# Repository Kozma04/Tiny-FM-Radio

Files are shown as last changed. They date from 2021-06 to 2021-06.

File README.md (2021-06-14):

# Tiny FM Radio v1 [Work in progress]
A small battery-powered FM Radio powered by the ATtiny3216 microcontroller.
Project sponsored by JLCPCB (https://jlcpcb.com/RAT)

It was originally intented to use the SI4703 FM tuner and some other ICs, but due to some PCB design mistakes and since this was originally a birthday project for my mother and I had to finish it ASAP, I was forced to drop some features for now and integrate in the project an FM tuner kit based on the HEX3653 IC I found at a local electronic components store.

This project's code is using SpenceKonde's megaTinyCore: https://github.com/SpenceKonde/megaTinyCore

# Present features
  * SH1106 monochrome OLED display (128x64 px, I2C interface)
  * TPA2005D1 1.4W audio amplifier fed by a PAM2401 5V/1A boost converter
  * 2W / 8Ohm speaker
  * 6 tactile buttons (up, down, left, right, ok and power)
  * 1200mAh LiPo battery
  * MCP73831 500mA LiPo / Li-Ion battery charger IC
  * Micro USB port for battery charging
  * AP2127K-3.3TRG1 3.3V / 400mA voltage regulator to supply the ICs. Uses the PAM2401 5V supply as input
  * ATtiny3216 microcontroller. Features:
    * Controls the HEX3653 FM tuner and the shutdown pins of the TPA2005D1 and PAM2401 ICs via a menu displayed on the OLED
    * Monitors the battery voltage
    * Shuts down the 5V supply when the battery voltage reaches a critical voltage

# Planned features (possible after fixing the PCB model)
  * SI4703-C19 FM tuner IC featuring volume control, RDS and more (needs external 32.768Khz oscillator)
  * Timekeeping using the MCP79402 real-time clock

Here is how the project looks like. __[Watch video!](https://youtu.be/wYINLay8BuY)__

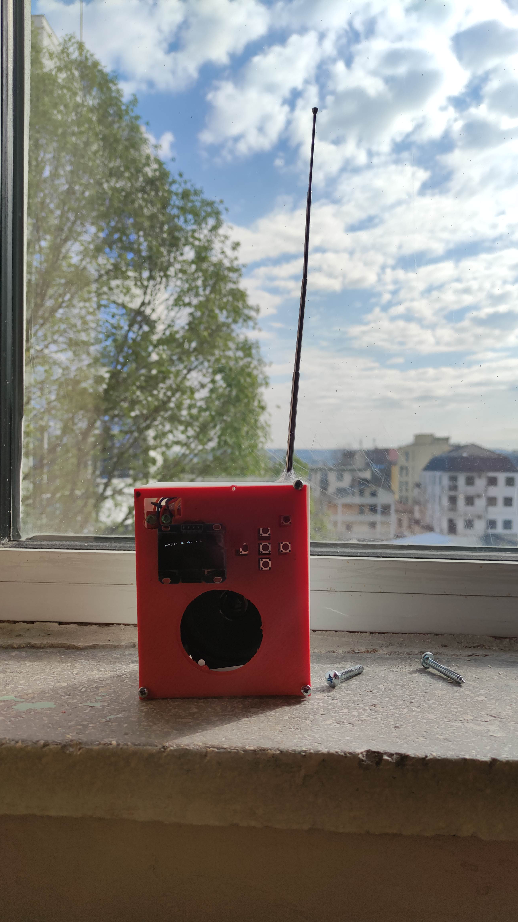
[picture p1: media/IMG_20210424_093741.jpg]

This was my first 3D Printed case :)

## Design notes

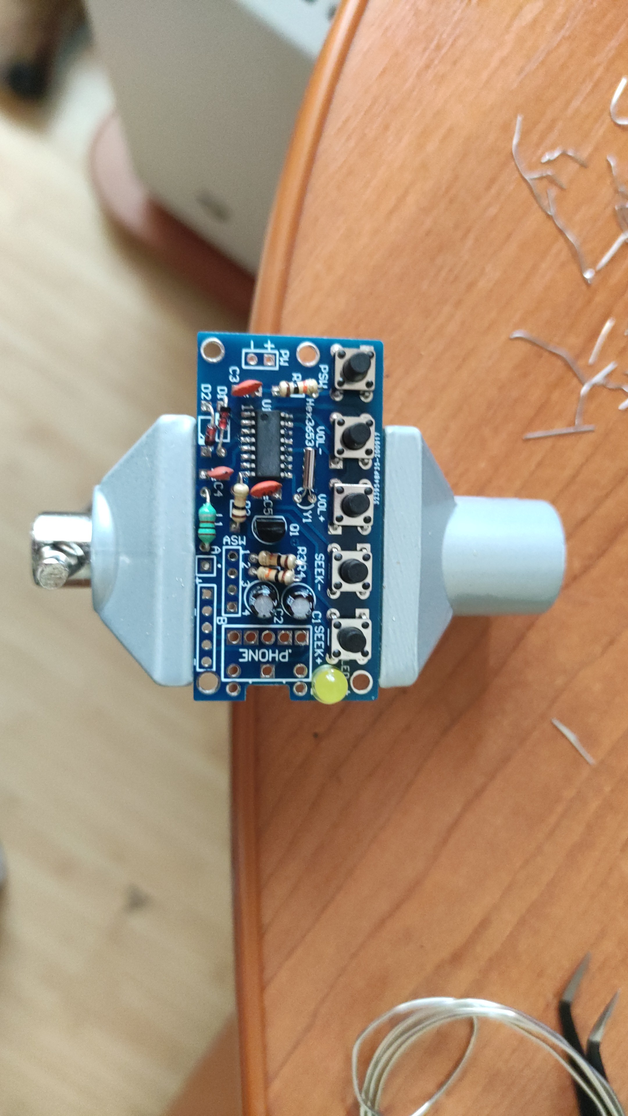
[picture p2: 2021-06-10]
media/IMG-20210422-WA0003.jpeg

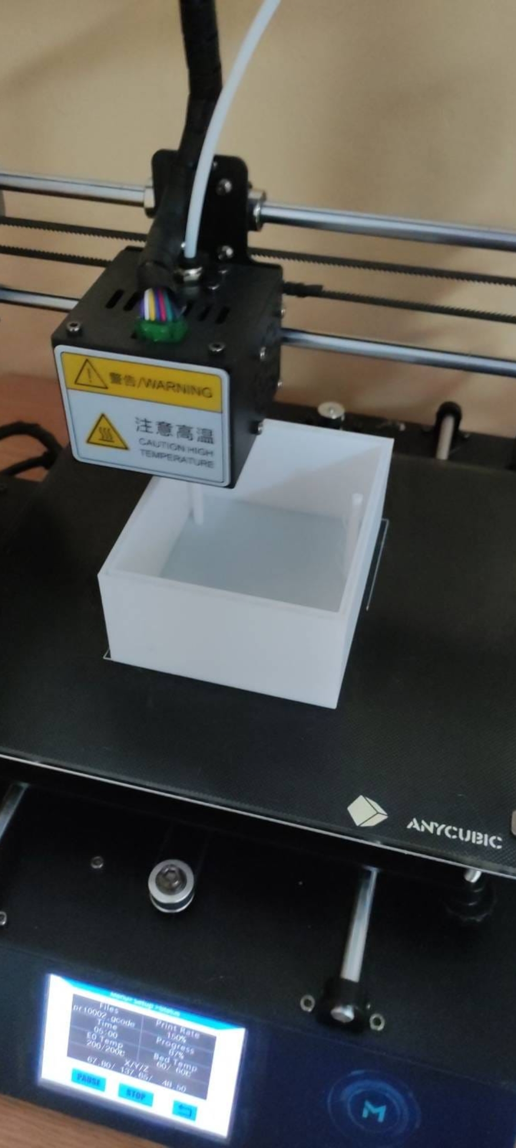
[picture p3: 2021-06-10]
media/wip.jpg

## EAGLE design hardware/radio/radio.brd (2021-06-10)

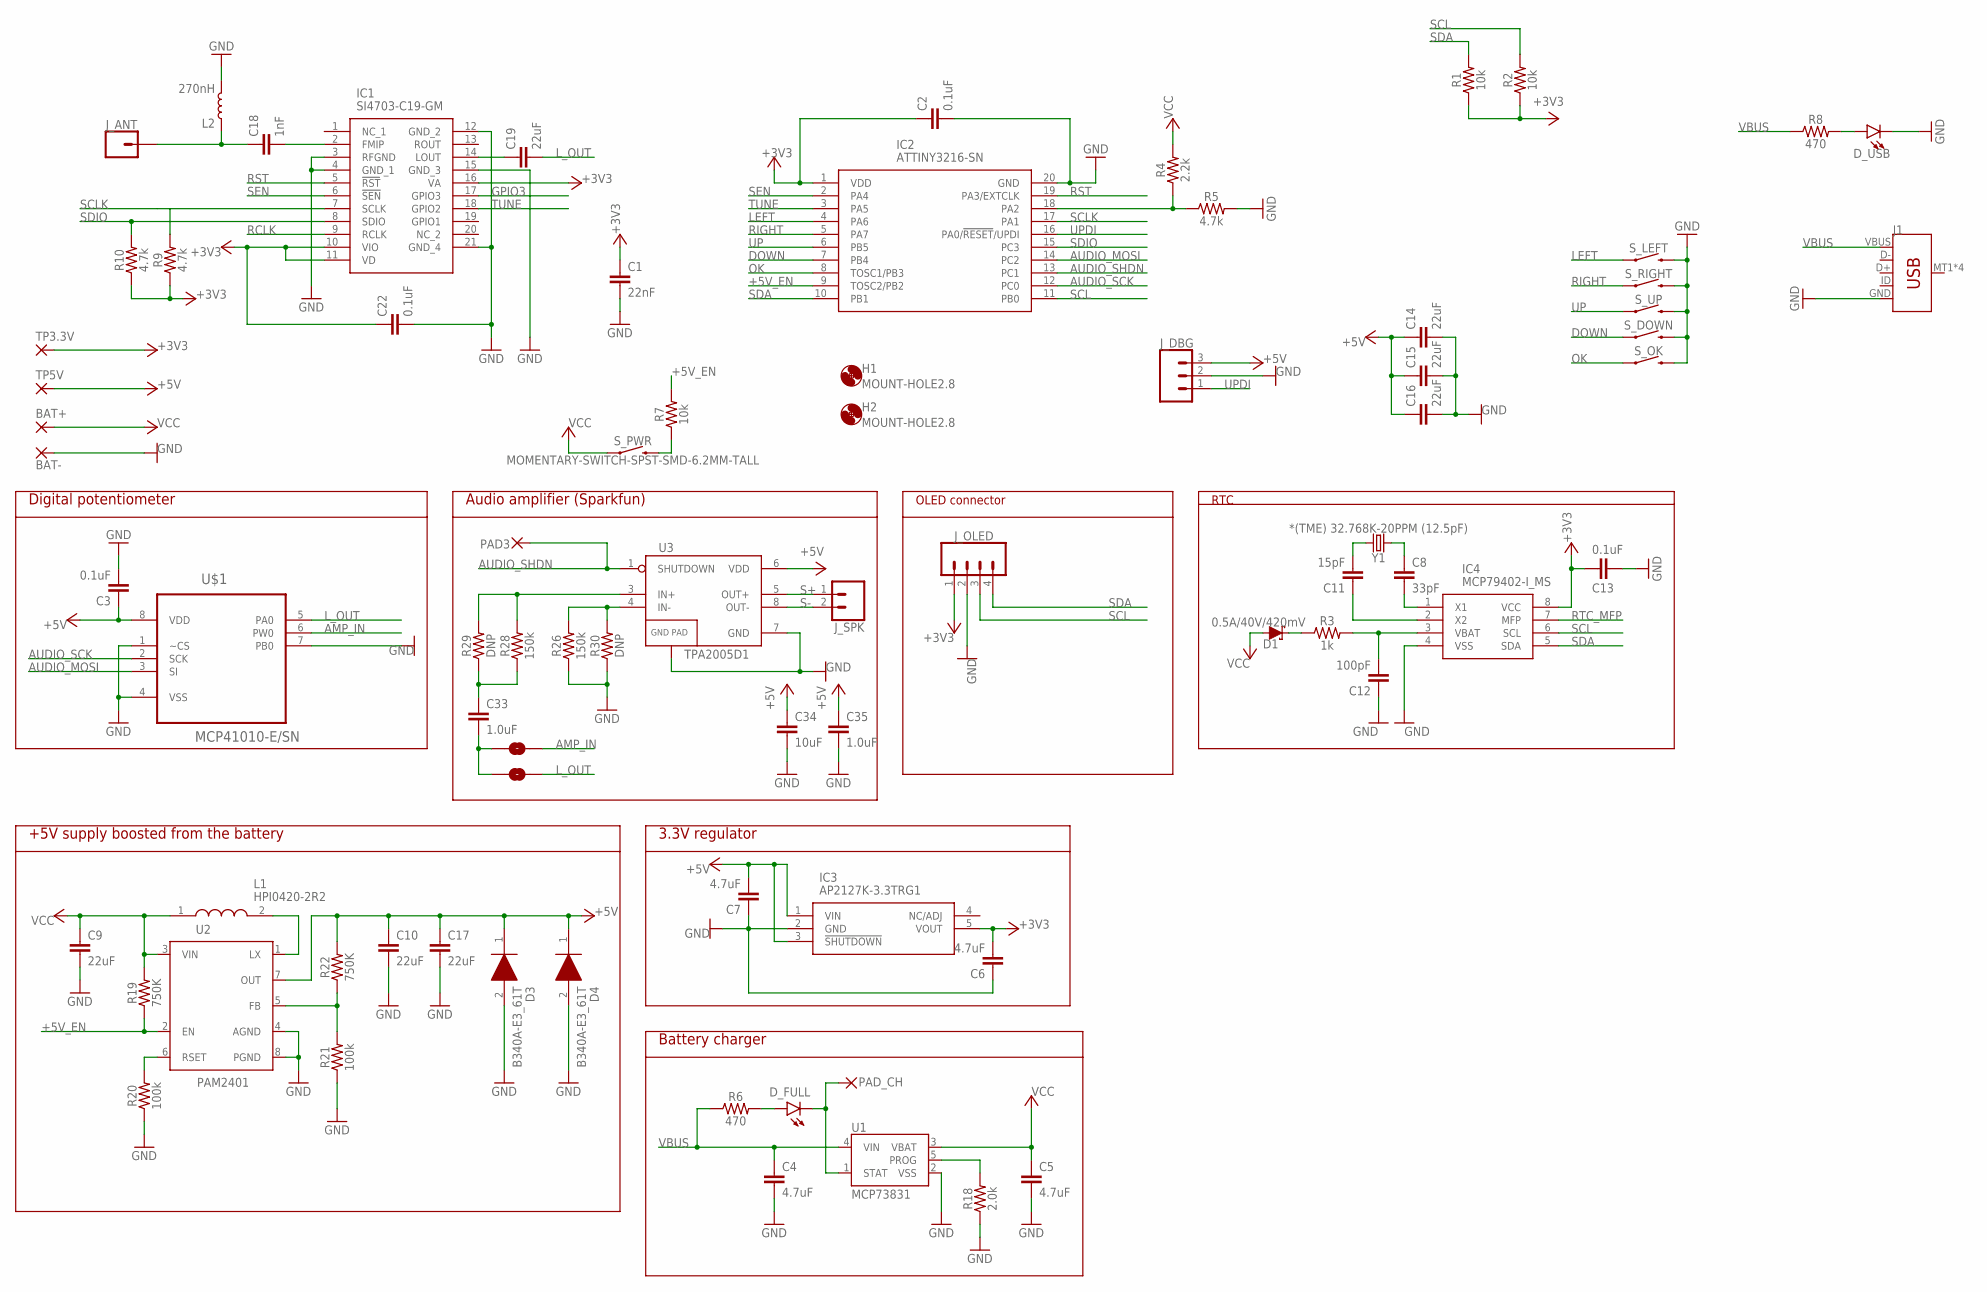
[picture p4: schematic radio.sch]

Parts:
BAT+: SMD2; SMD1,27-2,54
BAT-: SMD2; SMD1,27-2,54
C1: 22nF; 0603
C2, C3, C13, C22: 0.1uF; 0603
C4, C5, C6, C7: 4.7uF; 0603
C8: 33pF; 0603
C9, C10, C14, C15, C16, C17, C19: 22uF; 0805
C11: 15pF; 0603
C12: 100pF; 0603
C18: 1nF; 0603
C33, C35: 1.0uF; 0603
C34: 10uF; 0805
D1: 0.5A/40V/420mV; SOD-323
D3, D4: B340A-E3_61T; DIOM5127X229N
D_FULL: RED; LED_5MM
D_USB: LED5MM; LED_5MM
H1, H2: MOUNT-HOLE2.8; 2,8
IC1: SI4703-C19-GM; SI4703C19GM
IC2: ATTINY3216-SN; SOIC127P1030X265-20N
IC3: AP2127K-3.3TRG1; SOT95P282X145-5N
IC4: MCP79402-I_MS; SOP65P490X110-8N
J1: USB_MICRO-B_SMT; USB-MICROB
JP1, JP2: JUMPER-SMT_2_NO_NO-SILK; SMT-JUMPER_2_NO_NO-SILK
J_ANT: CONN_01; 1X01
J_DBG: CONN_03LOCK; 1X03_LOCK
J_OLED: CONN_04LOCK; 1X04_LOCK
J_SPK: CONN_02; 1X02
L1: HPI0420-2R2; HPI04202R2
L2: 270nH; 0805
PAD3: SMD2; SMD1,27-2,54
PAD_CH: SMD2; SMD1,27-2,54
R1, R2, R7: 10k; 0603
R3: 1k; 0603
R4: 2.2k; 0603
R5, R9, R10: 4.7k; 0603
R6, R8: 470; 0603
R18: 2.0k; 0603
R19, R22: 750K; 0603
R20, R21: 100k; 0603
R26, R28: 150k; 0603
R29, R30: DNP; 0603
S_DOWN: MOMENTARY-SWITCH-SPST-SMD-6.2MM-TALL; TACTILE_SWITCH_SMD_6.2MM_TALL
S_LEFT: MOMENTARY-SWITCH-SPST-SMD-6.2MM-TALL; TACTILE_SWITCH_SMD_6.2MM_TALL
S_OK: MOMENTARY-SWITCH-SPST-SMD-6.2MM-TALL; TACTILE_SWITCH_SMD_6.2MM_TALL
S_PWR: MOMENTARY-SWITCH-SPST-SMD-6.2MM-TALL; TACTILE_SWITCH_SMD_6.2MM_TALL
S_RIGHT: MOMENTARY-SWITCH-SPST-SMD-6.2MM-TALL; TACTILE_SWITCH_SMD_6.2MM_TALL
S_UP: MOMENTARY-SWITCH-SPST-SMD-6.2MM-TALL; TACTILE_SWITCH_SMD_6.2MM_TALL
TP3.3V, TP5V: SMD2; SMD1,27-2,54
U1: MCP73831; SOT23-5
U2: PAM2401; MSOP8
U3: TPA2005D1; POWER-SOP8
U$1: MCP41010-E/SN; SOIC127P600X175-8N
Y1: *(TME) 32.768K-20PPM (12.5pF); CRYSTAL-PTH-2X6-CYL

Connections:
+3V3: C1.1, C2.1, C3.1, C6.2, C13.2, C22.1, IC1.10 (VIO), IC1.11 (VD), IC1.16 (VA), IC2.1 (VDD), IC3.5 (VOUT), IC4.8 (VCC), J_OLED.1, R1.1, R2.1, R9.1, R10.1, TP3.3V.1, U$1.8 (VDD)
+5V: C7.2, C10.1, C14.1, C15.1, C16.1, C17.1, C34.1, C35.1, D3.1 (K), D4.1 (K), IC3.1 (VIN), IC3.3 (!SHUTDOWN), J_DBG.3, R22.2, TP5V.1, U2.7 (OUT), U3.6 (VDD)
+5V_EN: IC2.9 (TOSC2/PB2), R7.2, R19.1, U2.2 (EN)
AMP_IN: JP1.2, U$1.6 (PW0)
AUDIO_MOSI: IC2.14 (PC2), U$1.3 (SI)
AUDIO_SCK: IC2.12 (PC0), U$1.2 (SCK)
AUDIO_SHDN: IC2.13 (PC1), PAD3.1, U3.1 (SHUTDOWN)
DOWN: IC2.7 (PB4), S_DOWN.A2 (1)
GND: BAT-.1, C1.2, C2.2, C3.2, C4.2, C5.2, C6.1, C7.1, C9.2, C10.2, C12.1, C13.1, C14.2, C15.2, C16.2, C17.2, C22.2, C34.2, C35.2, D3.2 (A), D4.2 (A), D_USB.K (C), IC1.3 (RFGND), IC1.4 (GND_1), IC1.12 (GND_2), IC1.15 (GND_3), IC1.21 (GND_4), IC2.20 (GND), IC3.2 (GND), IC4.4 (VSS), J1.GND, J_DBG.2, J_OLED.2, L2.2, R5.2, R18.1, R20.1, R21.1, R26.1, R30.1, S_DOWN.B2 (2), S_LEFT.B2 (2), S_OK.B2 (2), S_RIGHT.B2 (2), S_UP.B2 (2), U1.2 (VSS), U2.4 (AGND), U2.8 (PGND), U3.7 (GND), U3.9 (GND), U$1.1 (~CS), U$1.4 (VSS), U$1.7 (PB0)
GPIO3: IC1.17 (GPIO3)
LEFT: IC2.4 (PA6), S_LEFT.A2 (1)
L_OUT: C19.2, JP2.2, U$1.5 (PA0)
unnamed: C18.2, IC1.2 (FMIP)
unnamed: C8.1, Y1.1
unnamed: C8.2, IC4.1 (X1)
unnamed: D_FULL.K (C), PAD_CH.1, U1.1 (STAT)
unnamed: D_FULL.A, R6.2
unnamed: C11.2, Y1.2
unnamed: C11.1, IC4.2 (X2)
unnamed: C12.2, IC4.3 (VBAT), R3.2
unnamed: D1.C, R3.1
unnamed: R18.2, U1.5 (PROG)
unnamed: R20.2, U2.6 (RSET)
unnamed: IC2.18 (PA2), R4.1, R5.1
unnamed: R7.1, S_PWR.B2 (2)
unnamed: D_USB.A, R8.2
unnamed: C18.1, J_ANT.1, L2.1
unnamed: C19.1, IC1.14 (LOUT)
unnamed: L1.2, U2.1 (LX)
unnamed: R21.2, R22.1, U2.5 (FB)
unnamed: R28.2, R29.2, U3.3 (IN+)
unnamed: R26.2, R30.2, U3.4 (IN-)
unnamed: C33.1, R28.1, R29.1
unnamed: C33.2, JP1.1, JP2.1
OK: IC2.8 (TOSC1/PB3), S_OK.A2 (1)
RCLK: IC1.9 (RCLK)
RIGHT: IC2.5 (PA7), S_RIGHT.A2 (1)
RST: IC1.5 (!RST), IC2.19 (PA3/EXTCLK)
RTC_MFP: IC4.7 (MFP)
S+: J_SPK.1, U3.5 (OUT+)
S-: J_SPK.2, U3.8 (OUT-)
SCL: IC2.11 (PB0), IC4.6 (SCL), J_OLED.3, R2.2
SCLK: IC1.7 (SCLK), IC2.17 (PA1), R9.2
SDA: IC2.10 (PB1), IC4.5 (SDA), J_OLED.4, R1.2
SDIO: IC1.8 (SDIO), IC2.15 (PC3), R10.2
SEN: IC1.6 (!SEN), IC2.2 (PA4)
TUNE: IC1.18 (GPIO2), IC2.3 (PA5)
UP: IC2.6 (PB5), S_UP.A2 (1)
UPDI: IC2.16 (PA0/!RESET!/UPDI), J_DBG.1
VBUS: C4.1, J1.VBUS, R6.1, R8.1, U1.4 (VIN)
VCC: BAT+.1, C5.1, C9.1, D1.A, L1.1, R4.2, R19.2, S_PWR.A2 (1), U1.3 (VBAT), U2.3 (VIN)

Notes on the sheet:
Digital potentiometer
Audio amplifier (Sparkfun)
+5V supply boosted from the battery
3.3V regulator
Battery charger
OLED connector
RTC

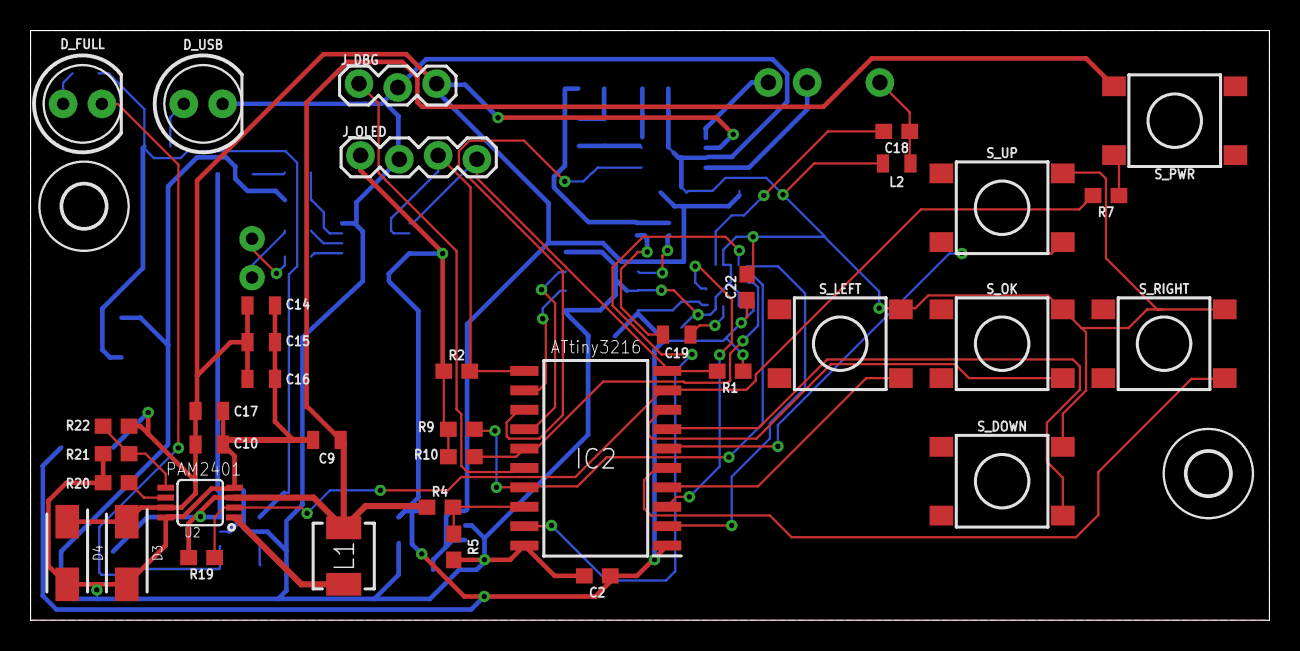
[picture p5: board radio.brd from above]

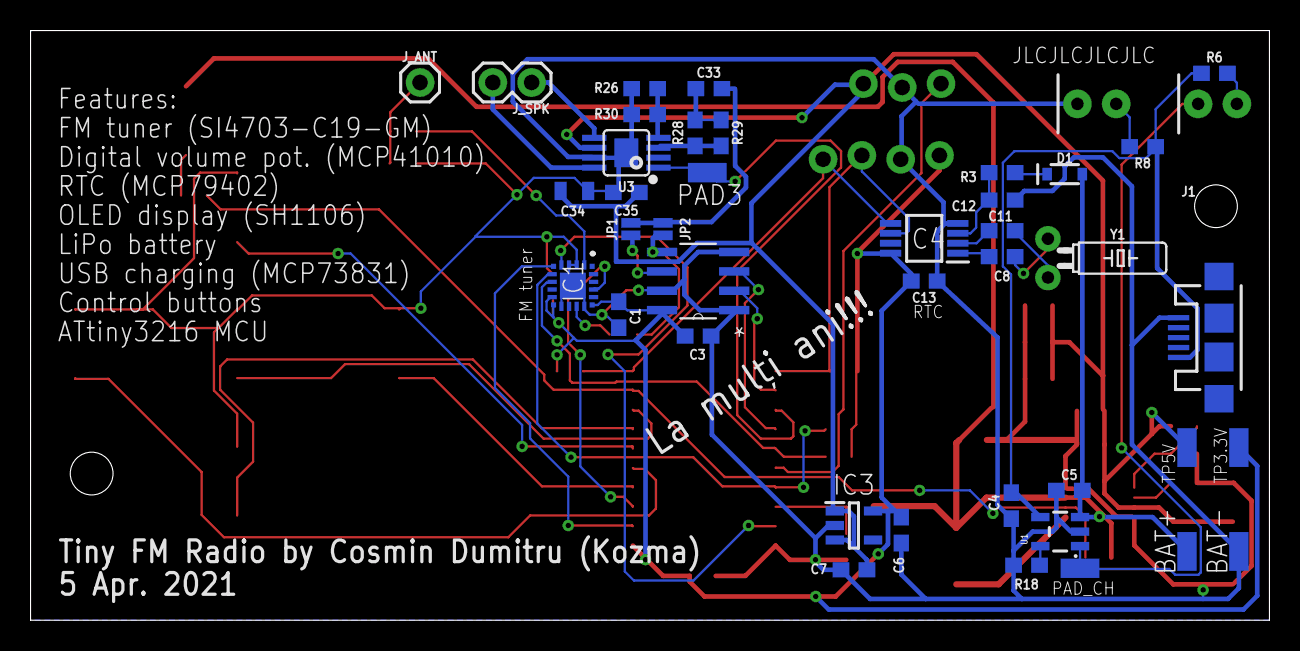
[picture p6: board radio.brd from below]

Board: 2 copper layers, 81.1 x 38.6 mm, 79 parts (40 on the bottom side), 48 nets.

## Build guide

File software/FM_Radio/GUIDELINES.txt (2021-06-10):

81.1mm x 38.6mm PCB
PCB drill 1: 3.5mm x 27.1mm
PCB drill 2: 77.1mm x 9.6mm
PCB drill diameter: 2.8mm
Holder PCB drill diameter: 4.2mm

Button dimensions: 6.2mm x 6.2mm
Power button: 74.9 x 32.7
Up: 63.6 x 27
Down: 63.6 x 9.1
Left: 53 x 18.1
Right: 74.2 x 18.1
Ok: 63.6 x 18.1

OLED header: 21.6 x 30.3

OFFSET LEFT AND RIGHT SIDES BY 1.2MM!

0.5mm tolerance
2.5mm thickness

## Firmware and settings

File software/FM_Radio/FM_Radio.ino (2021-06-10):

#include <Wire.h>
#include "font5x7.h"
#include "tinytwi.h"
#include "SH1106.h"

#define PIN_PWR   PIN_PB2
#define PIN_BAT   PIN_PA2
#define PIN_OK    PIN_PB3
#define PIN_UP    PIN_PB5
#define PIN_DOWN  PIN_PB4
#define PIN_LEFT  PIN_PA6
#define PIN_RIGHT PIN_PA7
#define PIN_ASHDN PIN_PC1

#define PIN_PSW   PIN_PA4
#define PIN_VOLM  PIN_PC3
#define PIN_VOLP  PIN_PC0
#define PIN_SEEKM PIN_PA1
#define PIN_SEEKP PIN_PA3

enum Action {
    LEFT, RIGHT, OK
};

struct Entry {
    char name[24] = {0};
    void (*callback)(Entry*, Action) = 0;
};

struct Menu {
    char name[16] = {0};
    Entry *entries[7];
    uint8_t nEntries;
};

Menu *menu;

uint8_t hovered;
bool mute = false;
int volume;

void renderMenu() {
    oled.clear();
    oled.setCursor(0, 0);
    oled.fontColor = INVERSE;
    oled.backColor = BLACK;
    oled.println(menu->name);
    for(int i = 0; i < menu->nEntries; i++) {
        if(i == hovered) oled.backColor = WHITE;
        oled.println(menu->entries[i]->name);
        if(i == hovered) oled.backColor = BLACK;
    }
}

void menuUp() {
    if(hovered > 0) hovered--;
    else hovered = menu->nEntries - 1;
}

void menuDown() {
    if(hovered < (menu->nEntries) - 1) hovered++;
    else hovered = 0;
}

void menuInteract(Action action) {
    if(menu->entries[hovered]->callback != 0)
        menu->entries[hovered]->callback(menu->entries[hovered], action);
}

void setMenu(Menu *newMenu) {
    hovered = 0;
    menu = newMenu;
}

void press(int pin) {
    digitalWrite(pin, LOW);
    pinMode(pin, OUTPUT);
    delay(100);
    pinMode(pin, INPUT);
    delay(100);
}

Menu home;
Entry eBattery;
Entry eShutdown;
Entry eMute;
Entry eVolume;
Entry eSeek;
Entry ePsw;

uint32_t t;

void shutdown() {
    oled.command(SH1106_DISPLAYOFF);
    delay(100);
    PORTB.OUTCLR = 1 << 2;
    for(;;);
}

void shutdownCallback(Entry *entry, Action action) {
    if((PORTB.IN & (1 << 3)) == 0) {
        t = millis();
        while((PORTB.IN & (1 << 3)) == 0) {
            if(millis() - t > 1500) {
                shutdown();
            }
        }
    }
}

void muteCallback(Entry *entry, Action action) {
    mute = !mute;
    if(mute) {
        strcpy(eMute.name, " Mute: DA");
        digitalWrite(PIN_ASHDN, LOW);
    }
    else {
        strcpy(eMute.name, " Mute: NU");
        digitalWrite(PIN_ASHDN, HIGH);
    }
}

void volumeCallback(Entry *entry, Action action) {
    if(action == LEFT) {
        press(PIN_VOLM);
    }
    else if(action == RIGHT) {
        press(PIN_VOLP);
    }
}

void seekCallback(Entry *entry, Action action) {
    if(action == LEFT) {
        press(PIN_SEEKM);
    }
    else if(action == RIGHT) {
        press(PIN_SEEKP);
    }
}

void pswCallback(Entry *entry, Action action) {
    press(PIN_PSW);
}

void initMenu() {
    setMenu(&home);
    strcpy(home.name, "Radio FM");
    home.nEntries = 6;
    home.entries[0] = &eBattery;
    home.entries[1] = &eMute;
    home.entries[2] = &eVolume;
    home.entries[3] = &eSeek;
    home.entries[4] = &ePsw;
    home.entries[5] = &eShutdown;

    strcpy(eBattery.name, " [no battery data]");
    strcpy(eMute.name, " Mute: NU");
    strcpy(eVolume.name, " Volum [- / +]");
    strcpy(eShutdown.name, " Oprire");
    strcpy(eSeek.name, " Canal [- / +]");
    strcpy(ePsw.name, " PSW (buton radio)");
    eShutdown.callback = shutdownCallback;
    eMute.callback = muteCallback;
    eVolume.callback = volumeCallback;
    eSeek.callback = seekCallback;
    ePsw.callback = pswCallback;
}

int appendInt(char *c, int t, int pos) {
    int p10 = pow(10, getNc(t) - 1);
    while(p10 > 0) {
        c[pos++] = '0' + (t / p10 % 10);
        p10 /= 10;
    }
    return pos;
}

void setup() {
    pinMode(PIN_ASHDN, OUTPUT);
    digitalWrite(PIN_ASHDN, LOW);
    PORTB.DIRCLR = 1 << 2;
    PORTB.DIRCLR = 1 << 5; // UP
    PORTB.PIN5CTRL = 1 << 3;
    uint32_t t = millis();
    bool ok = true;
    while(millis() - t < 1000) {
        if((PORTB.IN & (1 << 5)) != 0) {
            ok = false;
        }
    }
    if(!ok) {
        PORTB.DIRSET = 1 << 2;
        PORTB.OUTCLR = 1 << 2;
        for(;;);
    }

    PORTB.DIRSET = 1 << 2;
    PORTB.OUTSET = 1 << 2;
    PORTB.OUTCLR = 1 << 2;
    PORTB.OUTSET = 1 << 2;

    PORTB.DIRCLR = 1 << 3;
    PORTB.PIN3CTRL = 1 << 3;

    pinMode(PIN_UP, INPUT_PULLUP);
    pinMode(PIN_DOWN, INPUT_PULLUP);
    pinMode(PIN_LEFT, INPUT_PULLUP);
    pinMode(PIN_RIGHT, INPUT_PULLUP);
    analogReadResolution(10);

    TinyWire.begin();
    TinyWire.setSpeed(FAST_MODE);
    oled.setFont(font5x7, 5, 8, 1);

    oled.begin(FRAMEBUFFER_INT);

    oled.clear();
    oled.setCursor(0, 0);
    oled.println("Initializare...");
    oled.display();

    delay(500);
    oled.command(SH1106_DISPLAYOFF);
    delay(500);
    oled.command(SH1106_DISPLAYON);

    // set display orientation
    oled.command(0xc0 | 0x08);
    oled.command(0xa0 | 0x01);

    initMenu();

    pinMode(PIN_ASHDN, OUTPUT);
    digitalWrite(PIN_ASHDN, HIGH);
    for(int i = 0; i < 20; i++) press(PIN_VOLM);
}

uint8_t getNc(uint8_t x) {
    if(x >= 100) return 3;
    if(x >= 10) return 2;
    return 1;
}

uint32_t lastPress;
uint32_t f;

float bat = 1000;
float lowThreshold = 3.15; // Battery voltage considered low
float criticalThreshold = 3; // shutdown voltage

void loop() {
    f++;
    if(f % 10 == 0) {
        uint32_t val = 0;
        for(int i = 0; i < 10; i++)
            val += analogRead(PIN_BAT);
        val /= 10;
        bat = (val / 1024.f * 3.3f) * 6900.f / 4700.f;
        int p = min(100, max(0, int((bat - 3.f) / (4.2f - 3.f) * 100.f)));
        memset(eBattery.name, 0, 24);
        strcat(eBattery.name, " Bat.: ");
        int pos = 7;
        pos = appendInt(eBattery.name, int(bat), pos);
        eBattery.name[pos++] = '.';
        pos = appendInt(eBattery.name, int(bat * 100) % 100, pos);
        eBattery.name[pos++] = 'v';
        eBattery.name[pos++] = ' ';
        eBattery.name[pos++] = '/';
        eBattery.name[pos++] = ' ';
        pos = appendInt(eBattery.name, p, pos);
        eBattery.name[pos++] = '%';
    }

    /*
    oled.clear();
    oled.setCursor(0, 0);
    oled.fontColor = INVERSE;
    oled.backColor = WHITE;
    oled.print(" Readings:");
    oled.backColor = BLACK;
    oled.println(f);

    oled.print("Battery: ");
    oled.print(bat);
    oled.print("v / ");
    oled.print(int((bat - 3.f) / (4.2f - 3.f) * 100.f));
    oled.println("%");

    if(digitalRead(PIN_UP) == LOW) {
        press(PIN_VOLP);
        oled.println("Vol up");
    }
    else if(digitalRead(PIN_DOWN) == LOW) {
        press(PIN_VOLM);
        oled.println("Vol down");
    }
    else if(digitalRead(PIN_LEFT) == LOW) {
        press(PIN_SEEKM);
        oled.println("Seek -");
    }
    else if(digitalRead(PIN_RIGHT) == LOW) {
        press(PIN_SEEKP);
        oled.println("Seek +");
    }

    oled.display();
    delay(1000);*/

    if(millis() - lastPress >= 300) {
        bool pressed = false;
        if(digitalRead(PIN_UP) == LOW) {
            menuUp();
            pressed = true;
        }
        else if(digitalRead(PIN_DOWN) == LOW) {
            menuDown();
            pressed = true;
        }
        else if(digitalRead(PIN_LEFT) == LOW) {
            menuInteract(LEFT);
            pressed = true;
        }
        else if(digitalRead(PIN_RIGHT) == LOW) {
            menuInteract(RIGHT);
            pressed = true;
        }
        else if(digitalRead(PIN_OK) == LOW) {
            menuInteract(OK);
            pressed = true;
        }
        if(pressed) lastPress = millis();
    }

    renderMenu();
    if(bat < lowThreshold) {
        if(f % 80 > 40) {
            oled.invert(true);
            oled.backColor = WHITE;
        }
        else {
            oled.invert(false);
            oled.backColor = WHITE;
        }
        oled.print("BATERIE DESCARCATA"); // low battery
        oled.backColor = BLACK;
    }
    else oled.invert(false);
    if(bat < criticalThreshold) shutdown();
    oled.display();
}

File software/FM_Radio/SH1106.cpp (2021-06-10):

#include "SH1106.h"

#define sh1106_swap(a, b) { int16_t t = a; a = b; b = t; }

inline int16_t SH1106::width() {
    return SH1106_LCDWIDTH;
}

inline int16_t SH1106::height() {
    return SH1106_LCDHEIGHT;
}

void SH1106::drawPixel(int16_t x, int16_t y, uint8_t color) {
    if((x < 0) || (x >= width()) || (y < 0) || (y >= height()))
        return;
    drawPixelUnsafe(x, y, color);
}

void SH1106::drawPixelUnsafe(int16_t x, int16_t y, uint8_t color) {
    uint16_t pos = x + (y / 8) * SH1106_LCDWIDTH;
    static uint8_t val;
    buffer->read(pos, &val);
    switch (color) {
        case WHITE:   val |= 1 << (y & 7); break;
        case BLACK:   val &= ~(1 << (y & 7)); break;
        case INVERSE: val ^= 1 << (y & 7); break;
    }
    buffer->write(pos, val);
}

const uint8_t dif8[8] = {8, 7, 6, 5, 4, 3, 2, 1};
const uint8_t mask[8] = {0b1, 0b11, 0b111, 0b1111, 0b11111, 0b111111, 0b1111111, 0b11111111};

// takes an 8 bit portion from a 16-bit value which is shifted from the MSB to the right by rshift positions
uint8_t scroll(const uint8_t &a, const uint8_t &b, const uint8_t &rshift) {
    return (a << rshift) | (b >> dif8[rshift]);
}
// clear the last n bits from a
uint8_t clearBits(const uint8_t &a, const uint8_t &n) {
    return (a << n) >> n;//a & (~mask[n]); //(a >> n) << n;
}
// overlaps "fromlsb" bits (from MSB) from b over a. Ex.: lshift=3 -> result = aaaaabbb
uint8_t mergelsb(const uint8_t &a, const uint8_t &b, const uint8_t &fromlsb) {
    return clearBits(a, fromlsb) | (b << dif8[fromlsb]);
}

// overlaps "frommsb" bits (from MSB) from b over a. Ex.: lshift=3 -> result = aaaaabbb
uint8_t mergemsb(const uint8_t &a, const uint8_t &b, const uint8_t &frommsb) {
    return ((a >> frommsb) << frommsb) | (b >> dif8[frommsb]);
}

void ptr_swap(uint8_t **left, uint8_t **right) {
    uint8_t *swap = *left;
    *left = *right;
    *right = swap;
}

uint8_t bmpClusterA[SH1106_BMP_H_CLUSTER_SIZE], bmpClusterB[SH1106_BMP_H_CLUSTER_SIZE];
uint8_t *bmpA = bmpClusterA, *bmpB = bmpClusterB;
const uint8_t hcluster = SH1106_BMP_H_CLUSTER_SIZE;

inline constexpr bool check(const uint16_t &pos) {
    return pos >= 0 && pos < 1024;
}

void SH1106::drawBitmap(int16_t x, int16_t y, uint8_t bwidth, uint8_t bheight, Arr_Wrap<uint8_t> &bitmap, uint8_t loopWidth) {
    bheight /= 8;
    uint8_t h = 0, mod8 = y % 8, i, j, end;
    int8_t imod = 8 - mod8;
    int16_t pos = (y / 8) * SH1106_LCDWIDTH + x;
    uint8_t actualWidth = bwidth * loopWidth;
    int16_t bpos = 0;

    uint8_t midEnd = (mod8 == 0) ? (bheight) : (bheight-1);

    if(check(pos)) {
        buffer->readRange(pos, cluster, actualWidth);
        for(i = 0; i < actualWidth && i < SH1106_LCDWIDTH;) {
            end = min(bwidth, actualWidth - i);
            for(j = 0; j < end; i++, j++)
                cluster[i] = mergelsb(cluster[i], bmpA[j], imod);
        }
        buffer->writeRange(pos, cluster, actualWidth);
        h++;
    }
    if(mod8 == 0)bpos = -bwidth;
    if(mod8 > 0)pos += SH1106_LCDWIDTH;

    while(h < midEnd) {
        uint16_t nbpos = bpos + bwidth;
        bitmap.readRange(nbpos, bmpB, bwidth);
        if(check(pos)) {
            for(i = 0; i < actualWidth && i < SH1106_LCDWIDTH;) {
                end = min(bwidth, actualWidth - i);
                for(j = 0; j < end; i++, j++)
                    cluster[i] = (mod8 == 0 )? bmpB[j] : scroll(bmpB[j], bmpA[j], mod8);
                buffer->writeRange(pos, cluster, actualWidth);
            }
        }

        ptr_swap(&bmpA, &bmpB);

        pos += SH1106_LCDWIDTH, bpos = nbpos, h++;
    }

    if(mod8 > 0 && check(pos)) {
        bitmap.readRange(bwidth*(bheight-1), bmpA, bwidth);
        buffer->readRange(pos, cluster, actualWidth);
        for(i = 0; i < actualWidth && i < SH1106_LCDWIDTH;) {
            end = min(bwidth, actualWidth - i);
            for(j = 0; j < end; i++, j++)
                cluster[i] = mergemsb(0, bmpA[j], mod8);
        }
        buffer->writeRange(pos, cluster, actualWidth);
    }
}

void SH1106::begin(FramebufferAlloc fb, uint8_t vccstate, uint8_t i2caddr, bool reset) {
    if(fb == FRAMEBUFFER_INT)
        buffer = new Int_Arr<uint8_t>(SH1106_LCDHEIGHT * SH1106_LCDWIDTH / 8);

    _vccstate = vccstate;
    _i2caddr = i2caddr;

    // Init sequence for 128x64 OLED module
    command(SH1106_DISPLAYOFF);                    // 0xAE
    command(SH1106_SETDISPLAYCLOCKDIV);            // 0xD5
    command(0x80);                                  // the suggested ratio 0x80
    command(SH1106_SETMULTIPLEX);                  // 0xA8
    command(0x3F);
    command(SH1106_SETDISPLAYOFFSET);              // 0xD3
    command(0x00);                                   // no offset

    command(SH1106_SETSTARTLINE | 0x0);            // line #0 0x40
    command(SH1106_CHARGEPUMP);                    // 0x8D
    if (vccstate == SH1106_EXTERNALVCC)
      { command(0x10); }
    else
      { command(0x14); }
    command(SH1106_MEMORYMODE);                    // 0x20
    command(0x00);                                  // 0x0 act like ks0108
    command(SH1106_SEGREMAP | 0x1);
    command(SH1106_COMSCANDEC);
    command(SH1106_SETCOMPINS);                    // 0xDA
    command(0x12);
    command(SH1106_SETCONTRAST);                   // 0x81
    if (vccstate == SH1106_EXTERNALVCC) command(0x9F);
    else command(0xCF);
    command(SH1106_SETPRECHARGE);                  // 0xd9
    if (vccstate == SH1106_EXTERNALVCC) command(0x22);
    else command(0xF1);
    command(SH1106_SETVCOMDETECT);                 // 0xDB
    command(0x40);
    command(SH1106_DISPLAYALLON_RESUME);           // 0xA4
    command(SH1106_NORMALDISPLAY);                 // 0xA6

    command(SH1106_DISPLAYON);
}


void SH1106::invert(uint8_t i) {
    if (i) {
        command(SH1106_INVERTDISPLAY);
    } else {
        command(SH1106_NORMALDISPLAY);
    }
}

void SH1106::command(uint8_t c) {
    TinyWire.beginTransmission(_i2caddr);
    TinyWire.write(0); // Co = 0, D/C = 0
    TinyWire.write(c);
    TinyWire.endTransmission(true);
}

void SH1106::data(uint8_t c) {
    TinyWire.beginTransmission(_i2caddr);
    TinyWire.write(0x40); // Co = 0, D/C = 1
    TinyWire.write(c);
    TinyWire.endTransmission(true);
}

void SH1106::displayCluster(const uint8_t &size) {
    TinyWire.beginTransmission(_i2caddr);
    TinyWire.write(0x40);
    for (uint8_t l = 0; l < size; l++)
        TinyWire.write(cluster[l]);
    TinyWire.endTransmission(true);
}
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

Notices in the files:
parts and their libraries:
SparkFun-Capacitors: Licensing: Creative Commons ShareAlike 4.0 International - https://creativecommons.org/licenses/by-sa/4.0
